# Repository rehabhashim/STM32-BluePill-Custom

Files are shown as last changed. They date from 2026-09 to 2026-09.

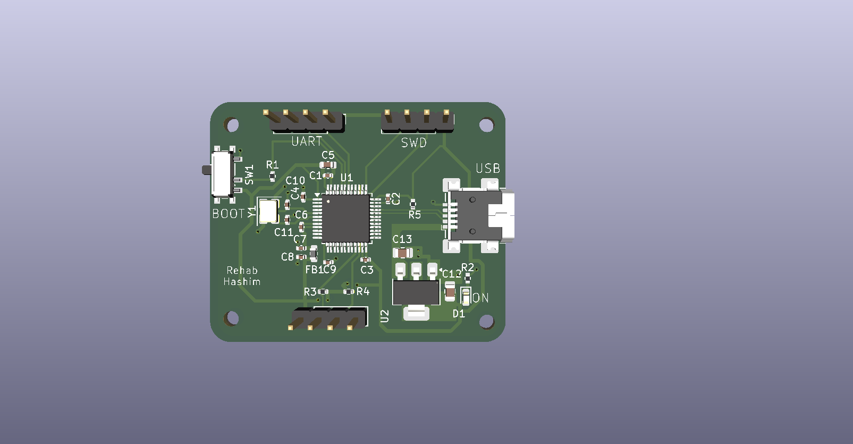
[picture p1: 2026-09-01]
STM32_3d.png

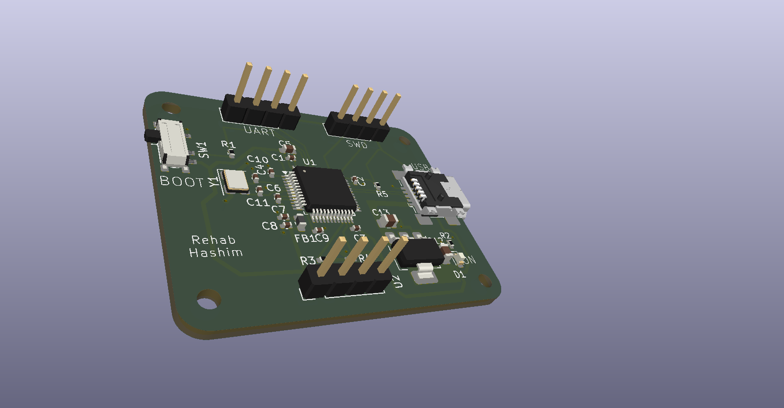
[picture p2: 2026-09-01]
bluepill_3d.png

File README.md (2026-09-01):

# STM32-BluePill-Custom
KiCad project for a custom STM32F103C8T6 (Blue Pill) development board. The PCB layout focuses on practical hardware design principles, including power integrity, ground planes, and DFM rules.

Key technical details:

The design centers on the STM32F103C8T6 (ARM Cortex-M3) microcontroller driven by a 16MHz external crystal. For robust power distribution, I implemented solid copper pours for the VBUS and +3.3V nets to improve thermal and current handling, backed by a continuous GND pour across the board to ensure a solid return path and minimize EMI. Signal integrity was prioritized by placing individual 100nF decoupling capacitors directly at the MCU's VDD pins to reduce loop inductance, alongside a dedicated VDDA filter network utilizing a 120Ω ferrite bead and capacitors for clean ADC performance. Mechanically, the board's outline and edge cuts were explicitly engineered to properly overhang the USB-B Mini connector, preventing any physical clearance issues post-fabrication.


STM32


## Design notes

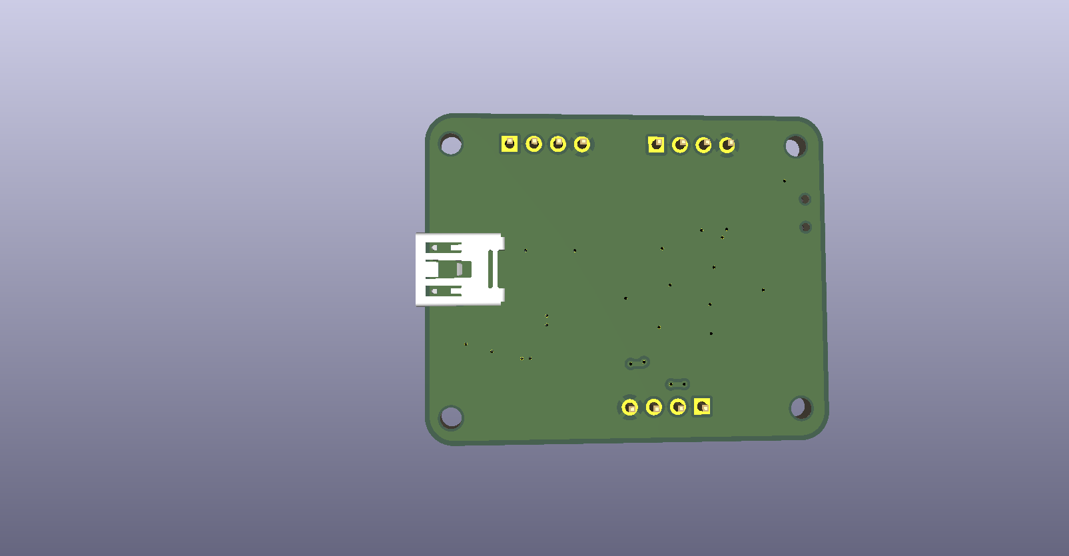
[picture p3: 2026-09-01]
bluepill_3d_back.png

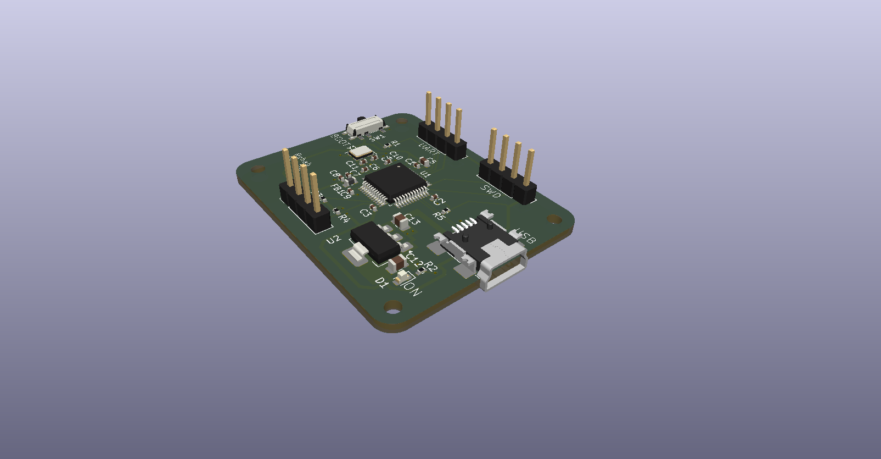
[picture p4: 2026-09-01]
stm32_3d_isometric.png

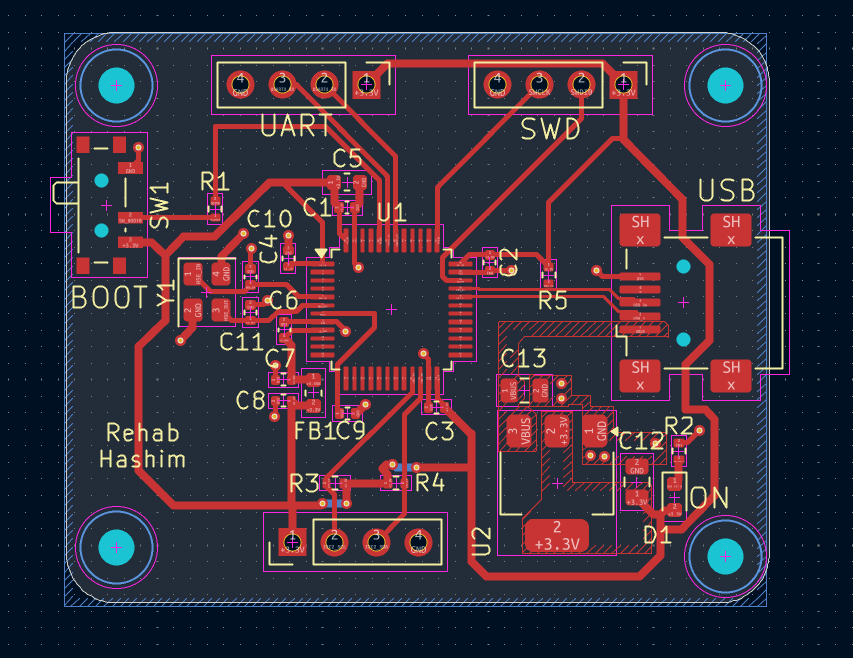
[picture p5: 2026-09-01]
stm32_pcb_routing.png

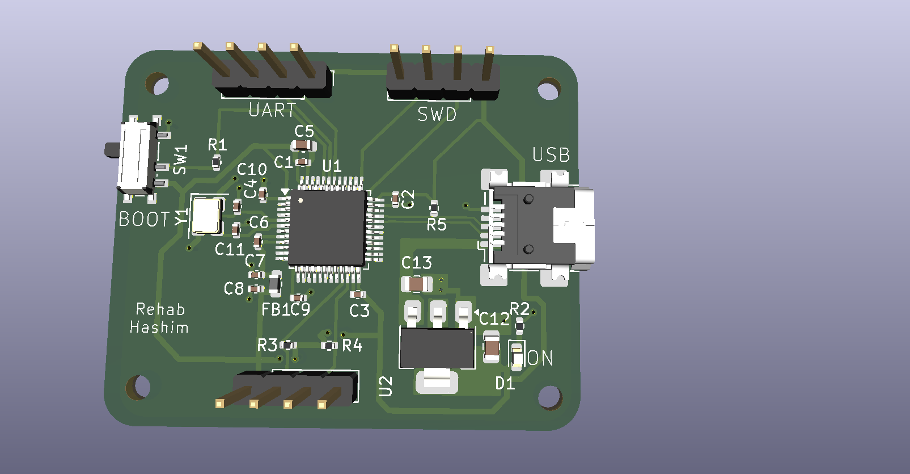
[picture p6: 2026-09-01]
stm32_3d_top_view.png

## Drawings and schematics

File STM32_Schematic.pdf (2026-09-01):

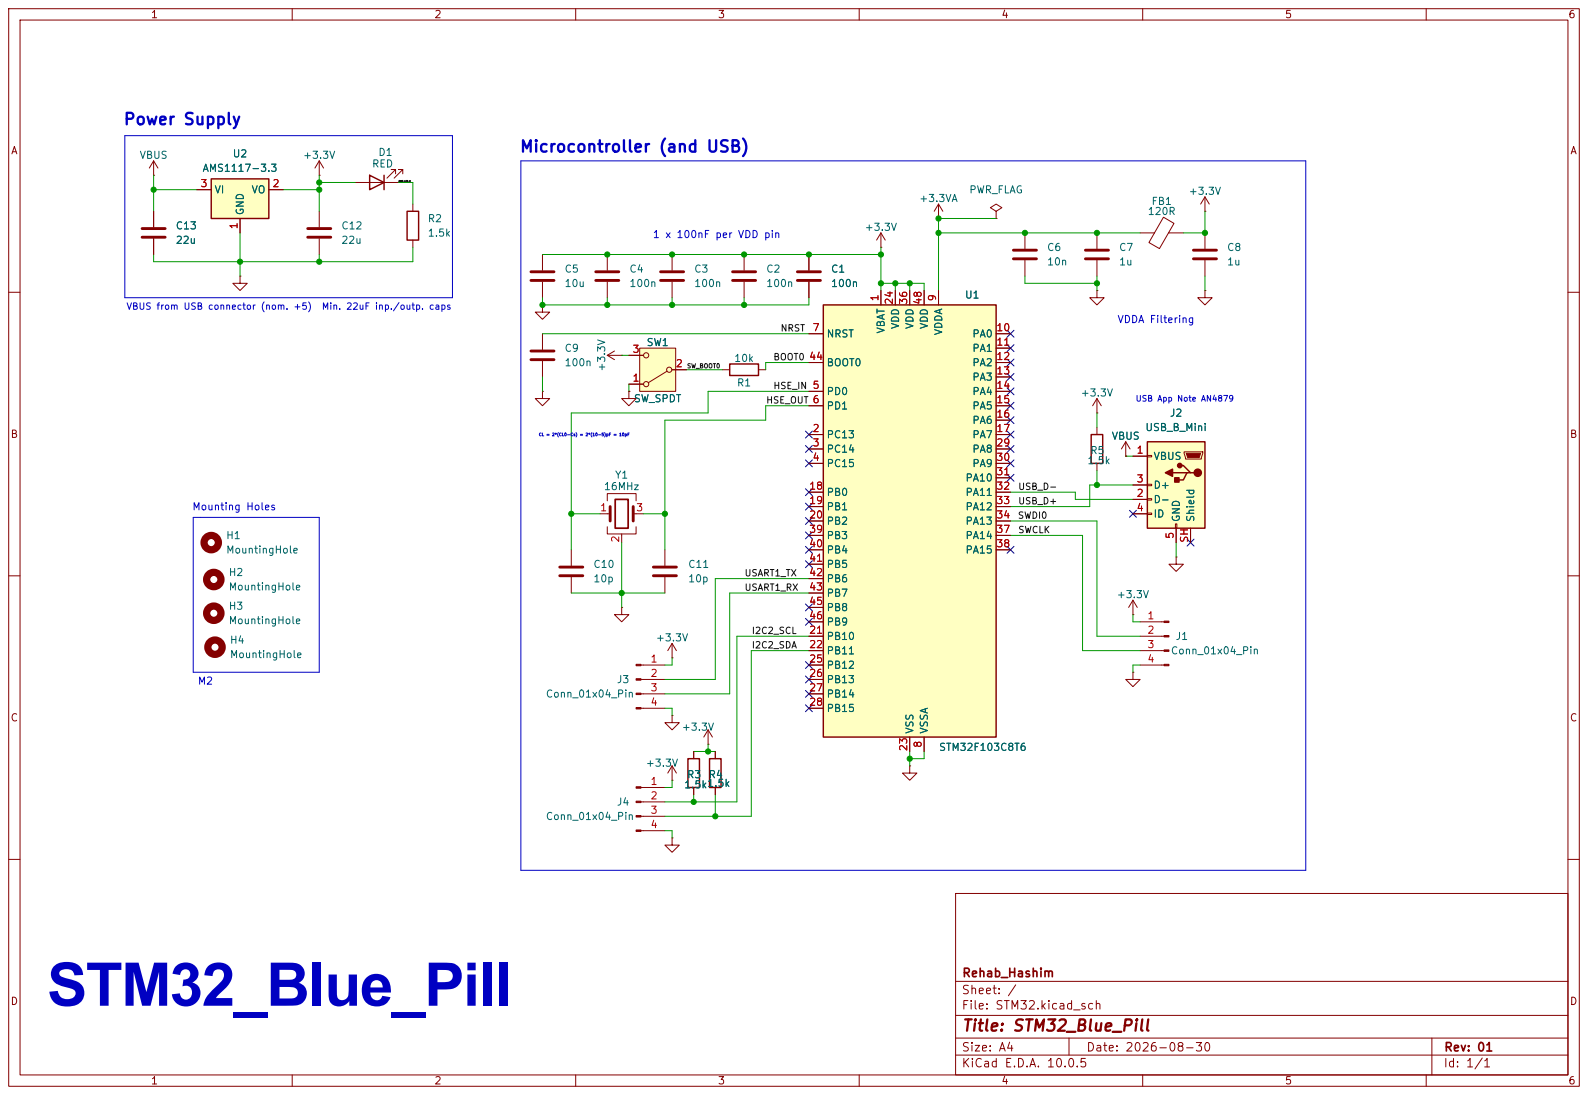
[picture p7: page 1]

Size: A4 | Rev: 01
KiCad E.D.A. 10.0.5 | Id: 1/1

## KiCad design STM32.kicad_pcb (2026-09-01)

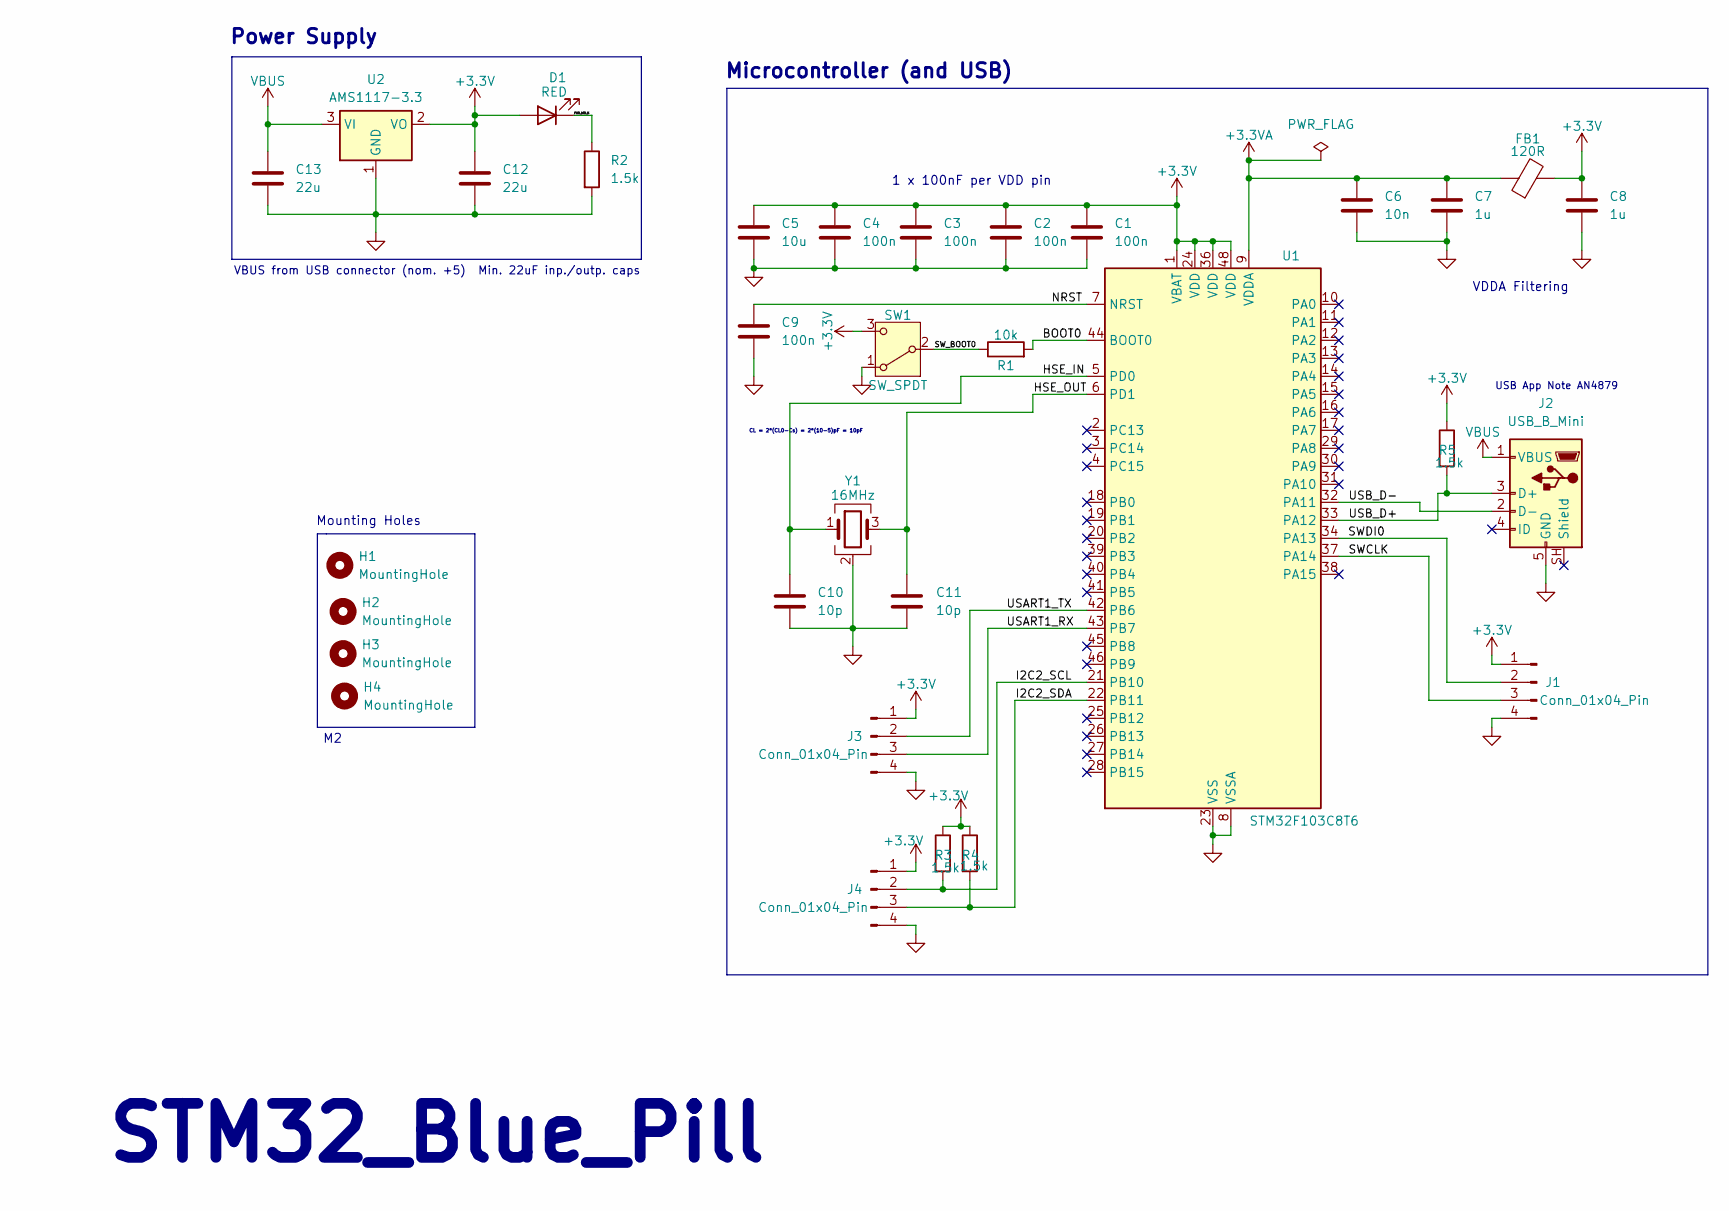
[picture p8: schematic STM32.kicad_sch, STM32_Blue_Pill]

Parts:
C1, C2, C3, C4, C9: 100n; C_0402_1005Metric
C5: 10u; C_0603_1608Metric
C6: 10n; C_0402_1005Metric
C7, C8: 1u; C_0402_1005Metric
C10, C11: 10p; C_0402_1005Metric
C12, C13: 22u; C_0805_2012Metric
D1: RED; LED_0603_1608Metric
FB1: 120R; L_0603_1608Metric
H1, H2, H3, H4: MountingHole; MountingHole_2.2mm_M2
J1, J3, J4: Conn_01x04_Pin; PinHeader_1x04_P2.54mm_Vertical
J2: USB_B_Mini; USB_Mini-B_Wuerth_65100516121_Horizontal
R1: 10k; R_0402_1005Metric
R2, R3, R4, R5: 1.5k; R_0402_1005Metric
SW1: SW_SPDT; SW_SPDT_PCM12
U1: STM32F103C8T6; LQFP-48_7x7mm_P0.5mm
U2: AMS1117-3.3; SOT-223-3_TabPin2
Y1: 16MHz; Crystal_SMD_3225-4Pin_3.2x2.5mm

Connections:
+3.3V: C1.1, C2.1, C3.1, C4.1, C5.1, C8.1, C12.1, D1.2 (A), FB1.2, J1.1, J3.1, J4.1, R3.1, R4.1, R5.1, SW1.3 (C), U1.1 (VBAT), U1.24 (VDD), U1.36 (VDD), U1.48 (VDD), U2.2 (VO)
+3.3VA: C6.1, C7.1, FB1.1, U1.9 (VDDA)
/BOOT0: R1.2, U1.44 (BOOT0)
/HSE_IN: C10.1, U1.5 (PD0), Y1.1
/HSE_OUT: C11.1, U1.6 (PD1), Y1.3
/I2C2_SCL: J4.2, R3.2, U1.21 (PB10)
/I2C2_SDA: J4.3, R4.2, U1.22 (PB11)
/NRST: C9.1, U1.7 (NRST)
/PWR_LED_K: D1.1 (K), R2.1
/SWCLK: J1.3, U1.37 (PA14)
/SWDI0: J1.2, U1.34 (PA13)
/SW_BOOT0: R1.1, SW1.2 (B)
/USART1_RX: J3.3, U1.43 (PB7)
/USART1_TX: J3.2, U1.42 (PB6)
/USB_D+: J2.3 (D+), R5.2, U1.33 (PA12)
/USB_D-: J2.2 (D-), U1.32 (PA11)
GND: C1.2, C2.2, C3.2, C4.2, C5.2, C6.2, C7.2, C8.2, C9.2, C10.2, C11.2, C12.2, C13.2, J1.4, J2.5 (GND), J3.4, J4.4, R2.2, SW1.1 (A), U1.8 (VSSA), U1.23 (VSS), U1.35 (VSS), U1.47 (VSS), U2.1 (GND), Y1.2 (G), Y1.4 (G)
VBUS: C13.1, J2.1 (VBUS), U2.3 (VI)

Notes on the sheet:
Microcontroller (and USB)
USB App Note AN4879
Mounting Holes
CL = 2*(CL0-Cs) = 2*(10-5)pF = 10pF
1 x 100nF per VDD pin
Power Supply
VDDA Filtering
STM32_Blue_Pill
VBUS from USB connector (nom. +5) Min. 22uF inp./outp. caps

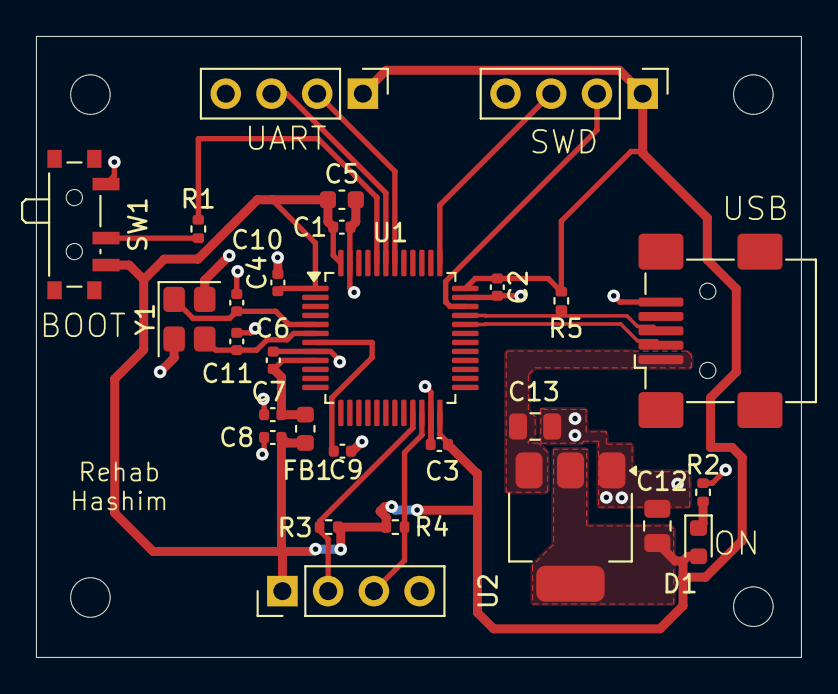
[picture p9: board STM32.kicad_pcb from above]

Board: 2 copper layers, 42.5 x 34.5 mm, 32 parts (0 on the bottom side), 18 nets.
